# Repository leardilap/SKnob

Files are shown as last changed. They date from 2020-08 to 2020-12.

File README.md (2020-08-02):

# SKnob
The safety knob for your stove

# Overall shape
- Two main PCBs with 24x17mm dimmentions joined with ~~flex PCB~~ 2 wires

# Battery
- CR1225 or similar with ~50mA could allow to be mounted in the top of one of the PCBs as the space is round in the middle
- Holder: Manufacturer Part Number 	BK-885-TR 

# Bluetooth-STM32
- Use the STM32WB55Cx chip 
- Workshop: https://www.youtube.com/watch?v=5Lp9cDBzG94&list=PLnMKNibPkDnGRfqUO1Q_-1nW-tOKfDQbc&index=1

# Antena
- Manufacturer 	PulseLarsen Antennas
Manufacturer Part Number 	W3008 

# Similar product
- https://burneralert.com/

# Commercial
- Don't be a SKnob, do you mean our safety knobs for our burnner?. this is how I protect my family everyday, no more sleepless nights, waking up at night just to check the stove. With SKnob I feel safe. Don't wait, be a hero today.

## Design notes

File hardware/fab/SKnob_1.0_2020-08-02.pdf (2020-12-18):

SKnob | Rev: 1.0
bozica.co | 2020-08-02
| Sou rce d | Pla ced | References | digikey# | manf | manf# | datasheet | Value | Footprint | Quantity
1 | | | C1, C2, C3, C4, C7, C8, C11, C12, C14, C21, C22, C23, C24, C27 | | | | | 100nF | C_0402_1005Metric | 14
2 | | | C16, C18 | | | | | 15pF | C_0402_1005Metric | 2
3 | | | C17, C19 | | | | | 9pF | C_0402_1005Metric | 2
4 | | | C5 | | | | | 100pF | C_0402_1005Metric | 1
5 | | | C6, C13, C15, C20, C25, C26 | | | | | 4.7uF | C_0805_2012Metric | 6
6 | | | R2, R4 | | | | | 10k | R_0402_1005Metric | 2
7 | | | R1 | | | | | 10M | R_0402_1005Metric | 1
8 | | | L1, L2 | 445-172893-1-ND | TDK Corporation | 445-172893-1-ND | https://product.tdk.com/info/en/catalog/datasheets/beads_automotive_power_mpz1608_en.pdf | 220 @ 100MHz | L_0603_1608Metric | 2
9 | | | L4 | 587-1720-1-ND | Taiyo Yuden | CBMF1608T100K | https://www.yuden.co.jp/productdata/catalog/wound02_e.pdf | 10uH | L_0603_1608Metric | 1
10 | | | D1 | 1N4148WL2-TPMSCT-ND | Micro Commercial Co | 1N4148WL2-TP | https://www.mccsemi.com/pdf/Products/1N4148WL2(DFN1006-2 L)-A.pdf | 1N4148 | D_0402_1005Metric | 1
11 | | | U2 | 497-15997-1-ND | STMicroelectronics | LIS2DE12TR | https://www.st.com/content/ccc/resource/technical/document/datasheet/group0/72/cb/80/a7/5e/fe/46/9d/DM00153214/files/DM00153214.pdf/jcr:content/translations/en.DM001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 | LIS2DE12TR | LIS2DE12TR | 1
12 | | | U1 | 497-18489-ND | STMicroelectronics | STM32WB55CGU6 | https://www.st.com/resource/en/datasheet/stm32wb55rg.pdf | STM32WB55Cx | STM32WB55Cx | 1
13 | | | U3 | 497-5026-1-ND | STMicroelectronics | USBLC6-2P6 | https://www.st.com/resource/en/datasheet/usblc6-2.pdf | USBLC6-2P6 | SOT-666 | 1
SKnob BOM | file:///home/lardilap/Projects/PCB/bozica/SKnob/hardware/fab/SKnob_1.0_2020-08-02.html
1 of 2 | 12/18/20, 10:32 AM

Sou
rce
d

Pla
ced | References | digikey# | manf | manf# | datasheet | Value | Footprint | Quantity
14 | Y1 | 490-18335-1-ND | Murata Electronics | XRCGB32M000F1H02R0

https://www.murata.c
om/products
/productdata
/8801065041950/SPEC-XRCGB32M000F1H02R0.p
df
32MHz | Crystal_SMD_2016-4Pi
n_2.0x1.6mm | 1
15 | Y2 | XC2744CT-ND | ECS Inc. | ECS-.327-9-12R-C-TR

https://www.ecsxtal.
com/store/pdf/ECX-12R.pdf
32.768kHz | Crystal_SMD_2012-2Pi
n_2.0x1.2mm | 1
16 | SW1 | SW1022CT-ND | Omron Electronics
Inc-EMC Div | B3U-3000P

https://omronfs.omro
n.com/en_US
/ecb/products
/pdf/en-b3u.pdf
SW_Push | SW_SPST_B3U-3000P | 1
17 | BZ1 | 2104-TE034003-1CT-ND | DB Unlimited | TE034003-1

https://dbunlimitedc
o.com/images
/product_images/2D-Drawings
/TE034003-1.pdf
TE034003-1 | TE034003-1 | 1
18 | FLT1 | 497-19088-1-ND | STMicroelectronics | MLPF-WB55-01E3

https://www.st.com
/resource
/en/datasheet/mlpf-wb55-01e3.pdf
MLPF-WB55-01E3 | MLPF-WB55-01E3 | 1
19 | ANT1 | 553-1530-1-ND | PulseLarsen Antennas | W3008

https://source.z2dat
a.com/2019/5/5/2/28
/32/733/W3008.pdf
W3008 | W3008 | 1
20 | BT1 | BK-885-CT-ND | MPD (Memory
Protection Devices) | BK-885-TR

https://www.memorypr
otectiondevices.com
/datasheets/BK-885-
datasheet.pdf
BK-885-TR | BatteryHolder_Keysto
ne_3000_1x12mm | 1
21 | Q1 | FDV301NCT-ND | ON Semiconductor | FDV301N

https://media.digike
y.com
/pdf/Data%20Sheets
/Fairchild%20PDFs
/FDV301N.pdf
FDV301N | SOT-23 | 1
22 | BATT1 | P183-ND | Panasonic - BSG | BR-1225

https://industrial.p
anasonic.com
/cdbs/www-data/pdf2
/AAA4000
/AAA4000C202.pdf
BR1225 | BR1225 | 1
23 | J2, J3 | 952-2280-ND | Harwin Inc. | M22-2510246 | https://cdn.harwin.c
om/pdfs/M22-251.pdf | Conn_01x02 | PinHeader_1x02_P2.00
mm_Vertical | 2
24 | J1 | WM9734CT-ND | Molex | 1051330001

https://www.molex.co
m/pdm_docs
/sd/1051330001_sd.pd
f
USB_B_Micro | USB_Micro-B_Molex-
105133-0001 | 1
SKnob BOM | file:///home/lardilap/Projects/PCB/bozica/SKnob/hardware/fab/SKnob_1.0_2020-08-02.html
2 of 2 | 12/18/20, 10:32 AM

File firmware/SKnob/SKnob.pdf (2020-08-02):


02/08/2020

## SKnob Project Configuration Report

# 1. Description

## 1.1. Project

Project Name | SKnob
Board Name | custom
Generated with: | STM32CubeMX 6.0.0
Date | 08/02/2020

## 1.2. MCU

MCU Series | STM32WB
MCU Line | STM32WBx5
MCU name | STM32WB55CCUx
MCU Package | UFQFPN48
MCU Pin number | 48

## 1.3. Core(s) information

Core(s) | ARM Cortex-M4

# 2. Pinout Configuration

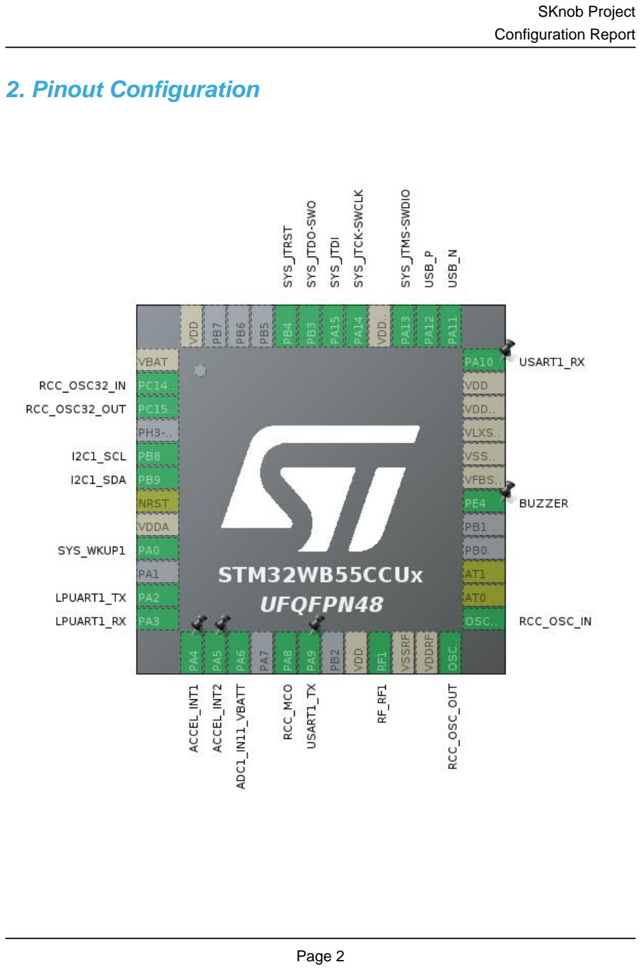
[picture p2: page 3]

# 3. Pins Configuration

Pin Number UFQFPN48 | Pin Name (function after reset) | Pin Type | Alternate Function(s) | Label
1 | VBAT | Power
2 | PC14-OSC32_IN | I/O | RCC_OSC32_IN
3 | PC15-OSC32_OUT | I/O | RCC_OSC32_OUT
5 | PB8 | I/O | I2C1_SCL
6 | PB9 | I/O | I2C1_SDA
7 | NRST | Reset
8 | VDDA | Power
9 | PA0 | I/O | SYS_WKUP1
11 | PA2 | I/O | LPUART1_TX
12 | PA3 | I/O | LPUART1_RX
13 | PA4 * | I/O | GPIO_Input | ACCEL_INT1
14 | PA5 * | I/O | GPIO_Input | ACCEL_INT2
15 | PA6 | I/O | ADC1_IN11 | ADC1_IN11_VBATT
17 | PA8 | I/O | RCC_MCO
18 | PA9 | I/O | USART1_TX
20 | VDD | Power
21 | RF1 | MonoIO | RF_RF1
22 | VSSRF | Power
23 | VDDRF | Power
24 | OSC_OUT | MonoIO | RCC_OSC_OUT
25 | OSC_IN | MonoIO | RCC_OSC_IN
26 | AT0 | NC
27 | AT1 | NC
30 | PE4 * | I/O | GPIO_Output | BUZZER
31 | VFBSMPS | Power
32 | VSSSMPS | Power
33 | VLXSMPS | Power
34 | VDDSMPS | Power
35 | VDD | Power
36 | PA10 | I/O | USART1_RX
37 | PA11 | I/O | USB_DM | USB_N
38 | PA12 | I/O | USB_DP | USB_P
39 | PA13 | I/O | SYS_JTMS-SWDIO
40 | VDDUSB | Power
41 | PA14 | I/O | SYS_JTCK-SWCLK
42 | PA15 | I/O | SYS_JTDI

Pin Number UFQFPN48 | Pin Name (function after reset) | Pin Type | Alternate Function(s) | Label
43 | PB3 | I/O | SYS_JTDO-SWO
44 | PB4 | I/O | SYS_JTRST
48 | VDD | Power

## * The pin is affected with an I/O function

# 4. Clock Tree Configuration

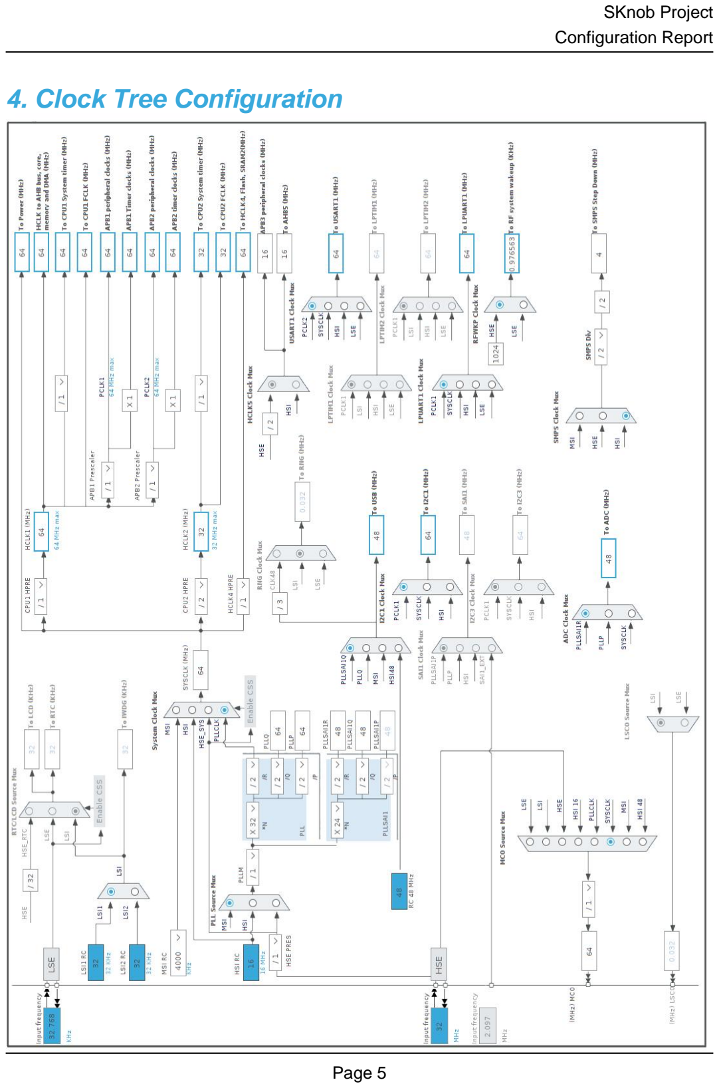
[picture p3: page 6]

# 5. Software Project

## 5.1. Project Settings

Name | Value
Project Name | SKnob
Project Folder | /home/luis/Projects/PCB/kicad/SKnob/firmware/SKnob
Toolchain / IDE | STM32CubeIDE
Firmware Package Name and Version | STM32Cube FW_WB V1.8.0
Application Structure | Basic
Generate Under Root | Yes
Do not generate the main() | No
Minimum Heap Size | 0x200
Minimum Stack Size | 0x400

## 5.2. Code Generation Settings

Name | Value
STM32Cube MCU packages and embedded software | Copy only the necessary library files
Generate peripheral initialization as a pair of '.c/.h' files | No
Backup previously generated files when re-generating | No
Keep User Code when re-generating | Yes
Delete previously generated files when not re-generated | Yes
Set all free pins as analog (to optimize the power consumption) | No
Enable Full Assert | No

## 5.3. Advanced Settings - Generated Function Calls

Rank | Function Name | IP Instance Name
1 | MX_GPIO_Init | GPIO
2 | SystemClock_Config | RCC
3 | MX_I2C1_Init | I2C1
4 | MX_USART1_UART_Init | USART1
5 | MX_USB_Device_Init | USB_DEVICE
6 | MX_ADC1_Init | ADC1
7 | MX_RF_Init | RF
8 | MX_LPUART1_UART_Init | LPUART1

# 6. Power Consumption Calculator report

## 6.1. Microcontroller Selection

Series | STM32WB
Line | STM32WBx5
MCU | STM32WB55CCUx
Datasheet | DS11929_Rev3

## 6.2. Parameter Selection

Temperature | 25
Vdd | 3.0

## 6.3. Battery Selection

Battery | Li-SOCL2(A3400)
Capacity | 3400.0 mAh
Self Discharge | 0.08 %/month
Nominal Voltage | 3.6 V
Max Cont Current | 100.0 mA
Max Pulse Current | 200.0 mA
Cells in series | 1
Cells in parallel | 1

## 6.4. Sequence

Step | Step1 | Step2
Mode | RUN | STOP2
Vdd | 3.0 | 3.0
Voltage Source | Battery | Battery
Range | Range1-High | NoRange/SMPS
Fetch Type | SRAM1 Flash-PowerDown | FLASH/ART/CACHE/BLE
CPU Frequency | 64 MHz | 0 Hz
Clock Configuration | HSI PLL Regulator_ON | ALL CLOCKS OFF BLE Regulator_ON
Clock Source Frequency | 16 MHz | 0 Hz

### Peripherals

Additional Cons. | 0 mA | 0 mA
Average Current | 8.8 mA | 1 nA
Duration | 0.1 ms | 0.9 ms
DMIPS | 80.0 | 0.0
Ta Max | 104.34 | 105
Category | In DS Table | In DS Table

## 6.5. Results

Sequence Time | 1 ms | Average Current | 880 µA
Battery Life | 5 months, 8 days, 5 hours | Average DMIPS | 8.0 DMIPS

## 6.6. Chart

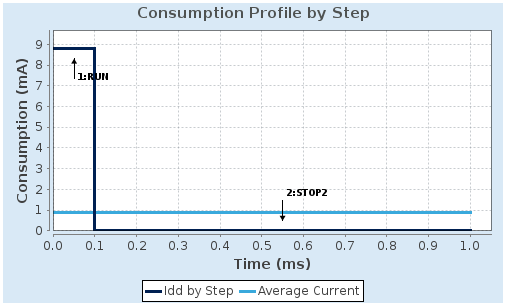
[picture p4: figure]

# 7. IPs and Middleware Configuration

## 7.1. ADC1 IN11: IN11 Single-ended mode: Vbat Channel

## 7.1.1. Parameter Settings:

### ADC_Settings:

Clock Prescaler | Asynchronous clock mode divided by 1
Resolution | ADC 12-bit resolution
Data Alignment | Right alignment
Scan Conversion Mode | Disabled
Continuous Conversion Mode | Disabled
Discontinuous Conversion Mode | Disabled
DMA Continuous Requests | Disabled
End Of Conversion Selection | End of single conversion
Overrun behaviour | Overrun data preserved
Low Power Auto Wait | Disabled

### ADC_Regular_ConversionMode:

Enable Regular Conversions | Enable
Enable Regular Oversampling | Disable
Number Of Conversion | 1
External Trigger Conversion Source | Regular Conversion launched by software
External Trigger Conversion Edge | None
Rank | 1
Channel | Channel 11
Sampling Time | 2.5 Cycles
Offset Number | No offset

### ADC_Injected_ConversionMode:

Enable Injected Conversions | Disable

### Analog Watchdog 1:

Enable Analog WatchDog1 Mode | false

### Analog Watchdog 2:

Enable Analog WatchDog2 Mode | false

### Analog Watchdog 3:

Enable Analog WatchDog3 Mode | false

## 7.2. GPIO

## 7.3. I2C1 I2C: I2C

## 7.3.1. Parameter Settings:

### Timing configuration:

Custom Timing | Disabled
I2C Speed Mode | Standard Mode
I2C Speed Frequency (KHz) | 100
Rise Time (ns) | 0
Fall Time (ns) | 0
Coefficient of Digital Filter | 0
Analog Filter | Enabled
Timing | 0x10707DBC *

### Slave Features:

Clock No Stretch Mode | Disabled
General Call Address Detection | Disabled
Primary Address Length selection | 7-bit
Dual Address Acknowledged | Disabled
Primary slave address | 0

## 7.4. LPUART1 Mode: Asynchronous

## 7.4.1. Parameter Settings:

### Basic Parameters:

Baud Rate | 209700
Word Length | 8 Bits (including Parity)
Parity | None
Stop Bits | 1

### Advanced Parameters:

Data Direction | Receive and Transmit
Single Sample | Disable
Prescaler | clock /1
Fifo Mode | FIFO mode disable
Txfifo Threshold | 1 eighth full configuration
Rxfifo Threshold | 1 eighth full configuration

### Advanced Features:

TX Pin Active Level Inversion | Disable

RX Pin Active Level Inversion | Disable
Data Inversion | Disable
TX and RX pins Swapping | Disable
Overrun | Enable
DMA on RX Error | Enable
MSB First | Disable

## 7.5. RCC High Speed Clock (HSE): Crystal/Ceramic Resonator Low Speed Clock (LSE) : Crystal/Ceramic Resonator mode: Master Clock Output

## 7.5.1. Parameter Settings:

### System Parameters:

VDD voltage (V) | 3.3
Instruction Cache | Enabled
Prefetch Buffer | Disabled
Data Cache | Enabled
Flash Latency(WS) | 3 WS (4 CPU cycle)

### RCC Parameters:

HSI Calibration Value | 16
MSI Calibration Value | 0
MSI Auto Calibration | Enabled
MSI State | Enabled
HSI State | Enabled
HSE Startup Timout Value (ms) | 100
LSE Startup Timout Value (ms) | 5000
LSE Drive Capability | LSE oscillator low drive capability

### Power Parameters:

Power Regulator Voltage Scale | Power Regulator Voltage Scale 1

### Peripherals Clock Configuration:

Generate the peripherals clock configuration | TRUE

## 7.6. RF mode: Activate RF1

## 7.7. SYS Debug: JTAG (5 pins) mode: System Wake-Up 1 Timebase Source: TIM17

## 7.8. USART1 Mode: Asynchronous

## 7.8.1. Parameter Settings:

### Basic Parameters:

Baud Rate | 115200
Word Length | 8 Bits (including Parity)
Parity | None
Stop Bits | 1

### Advanced Parameters:

Data Direction | Receive and Transmit
Over Sampling | 16 Samples
Single Sample | Disable
ClockPrescaler | clock /1
Fifo Mode | Disable
Txfifo Threshold | 1 eighth full configuration
Rxfifo Threshold | 1 eighth full configuration

### Advanced Features:

Auto Baudrate | Disable
TX Pin Active Level Inversion | Disable
RX Pin Active Level Inversion | Disable
Data Inversion | Disable
TX and RX Pins Swapping | Disable
Overrun | Enable
DMA on RX Error | Enable
MSB First | Disable

## 7.9. USB mode: Device (FS)

## 7.9.1. Parameter Settings:

### Basic Parameters:

Speed | Full Speed 12MBit/s

Physical interface | Internal Phy
Sof Enable | Disabled

### Power Parameters:

Low Power | Disabled
Link Power Management | Disabled
Battery Charging | Disabled

## 7.10. FREERTOS Interface: CMSIS_V2

## 7.10.1. Config parameters:

### API:

FreeRTOS API | CMSIS v2

### Versions:

FreeRTOS version | 10.2.1
CMSIS-RTOS version | 2.00

### MPU/FPU:

ENABLE_MPU | Disabled
ENABLE_FPU | Disabled

### Kernel settings:

USE_PREEMPTION | Enabled
CPU_CLOCK_HZ | SystemCoreClock
TICK_RATE_HZ | 1000
MAX_PRIORITIES | 56
MINIMAL_STACK_SIZE | 128
MAX_TASK_NAME_LEN | 16
USE_16_BIT_TICKS | Disabled
IDLE_SHOULD_YIELD | Enabled
USE_MUTEXES | Enabled
USE_RECURSIVE_MUTEXES | Enabled
USE_COUNTING_SEMAPHORES | Enabled
QUEUE_REGISTRY_SIZE | 8
USE_APPLICATION_TASK_TAG | Disabled
ENABLE_BACKWARD_COMPATIBILITY | Enabled
USE_PORT_OPTIMISED_TASK_SELECTION | Disabled
USE_TICKLESS_IDLE | Disabled
USE_TASK_NOTIFICATIONS | Enabled
RECORD_STACK_HIGH_ADDRESS | Disabled
OVERRIDE_DEFAULT_TICK_CONFIGURATION | Disabled

### Memory management settings:

Memory Allocation | Dynamic / Static
TOTAL_HEAP_SIZE | 3072
Memory Management scheme | heap_4

### Hook function related definitions:

USE_IDLE_HOOK | Disabled
USE_TICK_HOOK | Disabled
USE_MALLOC_FAILED_HOOK | Disabled
USE_DAEMON_TASK_STARTUP_HOOK | Disabled
CHECK_FOR_STACK_OVERFLOW | Disabled

### Run time and task stats gathering related definitions:

GENERATE_RUN_TIME_STATS | Disabled
USE_TRACE_FACILITY | Enabled
USE_STATS_FORMATTING_FUNCTIONS | Disabled

### Co-routine related definitions:

USE_CO_ROUTINES | Disabled
MAX_CO_ROUTINE_PRIORITIES | 2

### Software timer definitions:

USE_TIMERS | Enabled
TIMER_TASK_PRIORITY | 2
TIMER_QUEUE_LENGTH | 10
TIMER_TASK_STACK_DEPTH | 256

### Interrupt nesting behaviour configuration:

LIBRARY_LOWEST_INTERRUPT_PRIORITY | 15
LIBRARY_MAX_SYSCALL_INTERRUPT_PRIORITY | 5

### Added with 10.2.1 support:

MESSAGE_BUFFER_LENGTH_TYPE | size_t
USE_POSIX_ERRNO | Disabled

## 7.10.2. Include parameters:

### Include definitions:

vTaskPrioritySet | Enabled
uxTaskPriorityGet | Enabled
vTaskDelete | Enabled
vTaskCleanUpResources | Disabled
vTaskSuspend | Enabled
vTaskDelayUntil | Enabled
vTaskDelay | Enabled
xTaskGetSchedulerState | Enabled
xTaskResumeFromISR | Enabled
xQueueGetMutexHolder | Enabled

xSemaphoreGetMutexHolder | Disabled
pcTaskGetTaskName | Disabled
uxTaskGetStackHighWaterMark | Enabled
xTaskGetCurrentTaskHandle | Disabled
eTaskGetState | Enabled
xEventGroupSetBitFromISR | Disabled
xTimerPendFunctionCall | Enabled
xTaskAbortDelay | Disabled
xTaskGetHandle | Disabled
uxTaskGetStackHighWaterMark2 | Disabled

## 7.10.3. Advanced settings:

### Newlib settings (see parameter description first):

USE_NEWLIB_REENTRANT | Disabled

### Project settings (see parameter description first):

Use FW pack heap file | Enabled

## 7.11. USB_DEVICE Class For FS IP: Custom Human Interface Device Class (HID)

## 7.11.1. Parameter Settings:

### Class Parameters:

CUSTOM_HID_FS_BINTERVAL | 0x5 *
USBD_CUSTOM_HID_REPORT_DESC_SIZE (Total length for Report descriptor (IN ENDPOINT)) | 2
USBD_CUSTOMHID_OUTREPORT_BUF_SIZE (Maximum report buffer size (OUT ENDPOINT)) | 2

### Basic Parameters:

USBD_MAX_NUM_INTERFACES (Maximum number of supported interfaces) | 1
USBD_MAX_NUM_CONFIGURATION (Maximum number of supported configuration) | 1
USBD_MAX_STR_DESC_SIZ (Maximum size for the string descriptors) | 512
USBD_SELF_POWERED (Enabled self power) | Enabled
USBD_DEBUG_LEVEL (USBD Debug Level) | 0: No debug message
USBD_LPM_ENABLED (Link Power Management) | 1: Link Power Management supported

## 7.11.2. Device Descriptor:

### Device Descriptor:

VID (Vendor IDentifier) | 1155
LANGID_STRING (Language Identifier) | English(United States)
MANUFACTURER_STRING (Manufacturer Identifier) | STMicroelectronics

### Device Descriptor FS:

PID (Product IDentifier) | 22352 *
PRODUCT_STRING (Product Identifier) | STM32 Custom Human interface
CONFIGURATION_STRING (Configuration Identifier) | Custom HID Config
INTERFACE_STRING (Interface Identifier) | Custom HID Interface

### * User modified value

# 8. System Configuration

## 8.1. GPIO configuration

IP | Pin | Signal | GPIO mode | GPIO pull/up pull down | Max Speed | User Label
ADC1 | PA6 | ADC1_IN11 | Analog mode | No pull-up and no pull-down | n/a | ADC1_IN11_VBATT
I2C1 | PB8 | I2C1_SCL | Alternate Function Open Drain | Pull-up | Low
| PB9 | I2C1_SDA | Alternate Function Open Drain | Pull-up | Low
LPUART1 | PA2 | LPUART1_TX | Alternate Function Push Pull | No pull-up and no pull-down | Low
| PA3 | LPUART1_RX | Alternate Function Push Pull | No pull-up and no pull-down | Low
RCC | PC14-OSC32_IN | RCC_OSC32_IN | n/a | n/a | n/a
| PC15-OSC32_OU T | RCC_OSC32_O UT | n/a | n/a | n/a
| PA8 | RCC_MCO | Alternate Function Push Pull | No pull-up and no pull-down | Low
| OSC_OUT | RCC_OSC_OUT | n/a | n/a | n/a
| OSC_IN | RCC_OSC_IN | n/a | n/a | n/a
RF | RF1 | RF_RF1 | n/a | n/a | n/a
SYS | PA0 | SYS_WKUP1 | n/a | n/a | n/a
| PA13 | SYS_JTMS-SWDIO | n/a | n/a | n/a
| PA14 | SYS_JTCK-SWCLK | n/a | n/a | n/a
| PA15 | SYS_JTDI | n/a | n/a | n/a
| PB3 | SYS_JTDO-SWO | n/a | n/a | n/a
| PB4 | SYS_JTRST | n/a | n/a | n/a
USART1 | PA9 | USART1_TX | Alternate Function Push Pull | No pull-up and no pull-down | Low
| PA10 | USART1_RX | Alternate Function Push Pull | No pull-up and no pull-down | Low
USB | PA11 | USB_DM | Alternate Function Push Pull | No pull-up and no pull-down | Low | USB_N
| PA12 | USB_DP | Alternate Function Push Pull | No pull-up and no pull-down | Low | USB_P
GPIO | PA4 | GPIO_Input | Input mode | No pull-up and no pull-down | n/a | ACCEL_INT1
| PA5 | GPIO_Input | Input mode | No pull-up and no pull-down | n/a | ACCEL_INT2
| PE4 | GPIO_Output | Output Push Pull | No pull-up and no pull-down | Low | BUZZER

## 8.2. DMA configuration

## nothing configured in DMA service

## 8.3. NVIC configuration

## 8.3.1. NVIC

Interrupt Table | Enable | Preenmption Priority | SubPriority
Non maskable interrupt | true | 0 | 0
Hard fault interrupt | true | 0 | 0
Memory management fault | true | 0 | 0
Prefetch fault, memory access fault | true | 0 | 0
Undefined instruction or illegal state | true | 0 | 0
System service call via SWI instruction | true | 0 | 0
Debug monitor | true | 0 | 0
Pendable request for system service | true | 0 | 0
System tick timer | true | 0 | 0
USB low priority interrupt, USB wake-up interrupt through EXTI line 28 | true | 0 | 0
TIM1 trigger and commutation interrupts and TIM17 global interrupt | true | 0 | 0
PVD/PVM0/PVM2 interrupts through EXTI lines 16/31/33 | | unused
Flash global interrupt | | unused
RCC global interrupt | | unused
ADC1 global interrupt | | unused
USB high priority interrupt | | unused
CPU2 SEV interrupt through EXTI line 40 and PWR CPU2 HOLD wake-up interrupt | | unused
I2C1 event interrupt | | unused
I2C1 error interrupt | | unused
USART1 global interrupt | | unused
LPUART1 global interrupt | | unused
PWR switching on the fly, end of BLE activity, end of 802.15.4 activity, end of critical radio phase interrupt | | unused
FPU global interrupt | unused

## 8.3.2. NVIC Code generation

## Enabled interrupt Table Select for init sequence ordering Generate IRQ handler

## Call HAL handler

Non maskable interrupt | true | true | false
Hard fault interrupt | true | true | false
Memory management fault | true | true | false
Prefetch fault, memory access fault | true | true | false
Undefined instruction or illegal state | true | true | false

Enabled interrupt Table | Select for init sequence ordering | Generate IRQ handler | Call HAL handler
System service call via SWI instruction | true | false | false
Debug monitor | true | true | false
Pendable request for system service | true | false | false
System tick timer | true | false | false
USB low priority interrupt, USB wake-up interrupt through EXTI line 28 | true | true | true
TIM1 trigger and commutation interrupts and TIM17 global interrupt | true | true | true

### * User modified value

# 9. System Views

## 9.1. Category view 9.1.1. Current

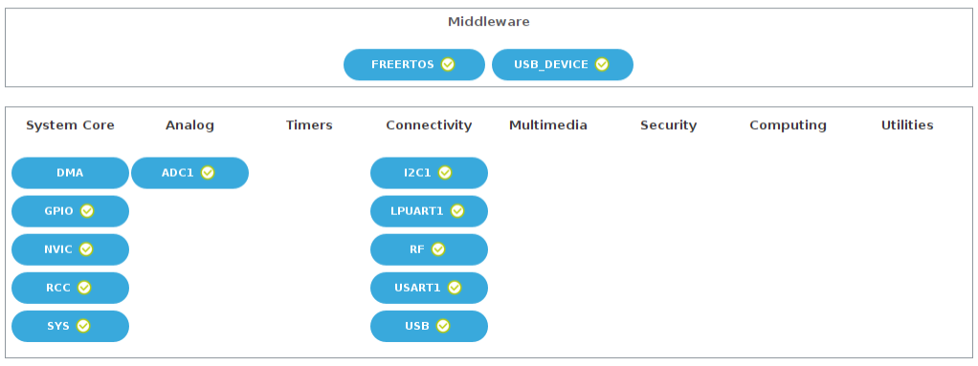
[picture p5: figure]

# 10. Software Pack Report

## 10.1. Software Pack selected

Vendor | Name | Version | Component
STMicroelectronic s | FreeRTOS | 0.0.1 | Class : CMSIS Group : RTOS2 SubGroup : FreeRTOS Version : 10.2.0 Class : RTOS Group : Core Version : 10.2.0
STMicroelectronic s | USB_DEVICE | 3.0.0 | Class : USB Group : USB Device SubGroup : Custom HID FS Version : 3.0

# 11. Docs & Resources

Type | Link
Datasheet | http://www.st.com/resource/en/datasheet/DM00344191.pdf
Reference manual | http://www.st.com/resource/en/reference_manual/DM00318631.pdf
Programming manual | http://www.st.com/resource/en/programming_manual/DM00046982.pdf
Programming manual | http://www.st.com/resource/en/programming_manual/DM00104451.pdf
Errata sheet | http://www.st.com/resource/en/errata_sheet/DM00383256.pdf
Application note | http://www.st.com/resource/en/application_note/CD00167594.pdf
Application note | http://www.st.com/resource/en/application_note/CD00211314.pdf
Application note | http://www.st.com/resource/en/application_note/CD00264342.pdf
Application note | http://www.st.com/resource/en/application_note/CD00264379.pdf
Application note | http://www.st.com/resource/en/application_note/DM00042534.pdf
Application note | http://www.st.com/resource/en/application_note/DM00072315.pdf
Application note | http://www.st.com/resource/en/application_note/DM00073742.pdf
Application note | http://www.st.com/resource/en/application_note/DM00081379.pdf
Application note | http://www.st.com/resource/en/application_note/DM00085385.pdf
Application note | http://www.st.com/resource/en/application_note/DM00087593.pdf
Application note | http://www.st.com/resource/en/application_note/DM00151811.pdf
Application note | http://www.st.com/resource/en/application_note/DM00160482.pdf
Application note | http://www.st.com/resource/en/application_note/DM00220769.pdf
Application note | http://www.st.com/resource/en/application_note/DM00227538.pdf
Application note | http://www.st.com/resource/en/application_note/DM00257177.pdf
Application note | http://www.st.com/resource/en/application_note/DM00272912.pdf
Application note | http://www.st.com/resource/en/application_note/DM00226326.pdf
Application note | http://www.st.com/resource/en/application_note/DM00236305.pdf
Application note | http://www.st.com/resource/en/application_note/DM00355687.pdf

Application note | http://www.st.com/resource/en/application_note/DM00311483.pdf
Application note | http://www.st.com/resource/en/application_note/DM00315319.pdf
Application note | http://www.st.com/resource/en/application_note/DM00380469.pdf
Application note | http://www.st.com/resource/en/application_note/DM00470410.pdf
Application note | http://www.st.com/resource/en/application_note/DM00395696.pdf
Application note | http://www.st.com/resource/en/application_note/DM00493651.pdf
Application note | http://www.st.com/resource/en/application_note/DM00535045.pdf
Application note | http://www.st.com/resource/en/application_note/DM00504903.pdf
Application note | http://www.st.com/resource/en/application_note/DM00556293.pdf
Application note | http://www.st.com/resource/en/application_note/DM00600032.pdf
Application note | http://www.st.com/resource/en/application_note/DM00403796.pdf
Application note | http://www.st.com/resource/en/application_note/DM00429003.pdf
Application note | http://www.st.com/resource/en/application_note/DM00513965.pdf
Application note | http://www.st.com/resource/en/application_note/DM00536349.pdf
Application note | http://www.st.com/resource/en/application_note/DM00556294.pdf
Application note | http://www.st.com/resource/en/application_note/DM00571230.pdf
Application note | http://www.st.com/resource/en/application_note/DM00600575.pdf
Application note | http://www.st.com/resource/en/application_note/DM00492814.pdf
Application note | http://www.st.com/resource/en/application_note/DM00598033.pdf
Application note | http://www.st.com/resource/en/application_note/DM00642959.pdf
Application note | http://www.st.com/resource/en/application_note/DM00643581.pdf
Application note | http://www.st.com/resource/en/application_note/DM00674475.pdf
Application note | http://www.st.com/resource/en/application_note/DM00652728.pdf
Application note | http://www.st.com/resource/en/application_note/DM00704246.pdf

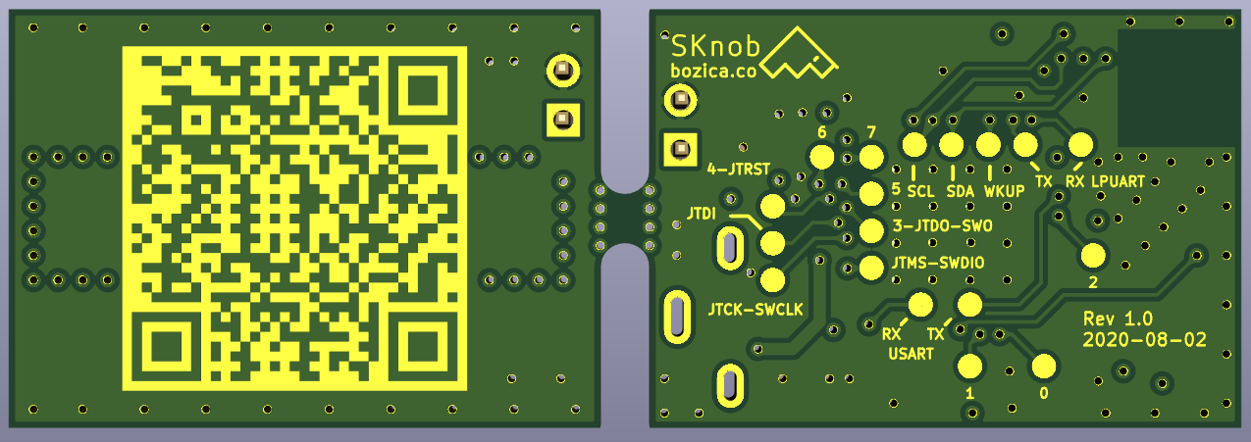
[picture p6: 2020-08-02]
hardware/images/PCB_3D_BOTTOM.png

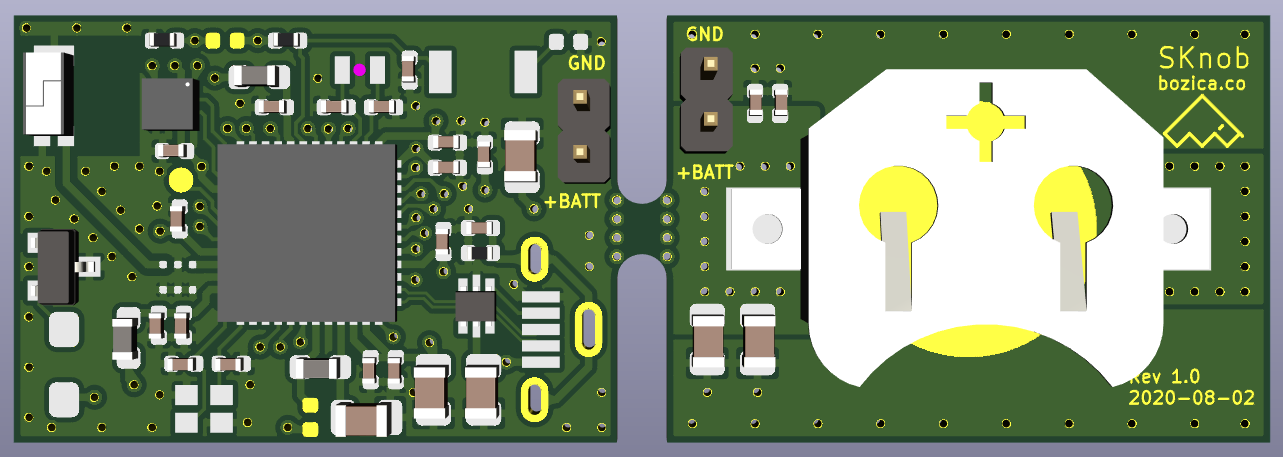
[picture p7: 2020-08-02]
hardware/images/PCB_3D_TOP.png

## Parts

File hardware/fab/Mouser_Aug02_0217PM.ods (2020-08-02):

SHOPPING BASKET
This is not an invoice
02-Aug-20 14:17:06
 | Mouser No | Mfr. No | Manufacturer | Customer No | Description | RoHS | Lifecycle | Order Qty. | Price (EUR) | Ext.: (EUR)
1 | 511-LIS2DE12TR | LIS2DE12TR | STMicroelectronics |  | Accelerometers CONSUMER MEMS | RoHS Compliant |  | 10 | 1,01 € | 10,10 €
2 | 673-W3008 | W3008 | Pulse |  | Antennas 2.4GHz BlueTooth Ceramic Antenna | RoHS Compliant |  | 10 | 1,12 € | 11,20 €
3 | 538-105133-0001 | 105133-0001 | Molex |  | USB Connectors MICRO USB B RECPT VERTICAL | RoHS Compliant |  | 10 | 0,80 € | 8,00 €
4 | 963-CBMF1608T100K | CBMF1608T100K | Taiyo Yuden |  | Fixed Inductors 0603 10uH 468mOhms +/-10% 115mA | RoHS Compliant |  | 10 | 0,139 € | 1,39 €
By submitting your order you agree to these terms and conditions. (https://www.mouser.de/saleterms) |  |  |  |  |  |  |  |  | Merchandise Total: | 30,69 €
Prices are reflected at the date and time shown. |  |  |  |  |  |  |  |  | Delivery Charge: | 20,00 €

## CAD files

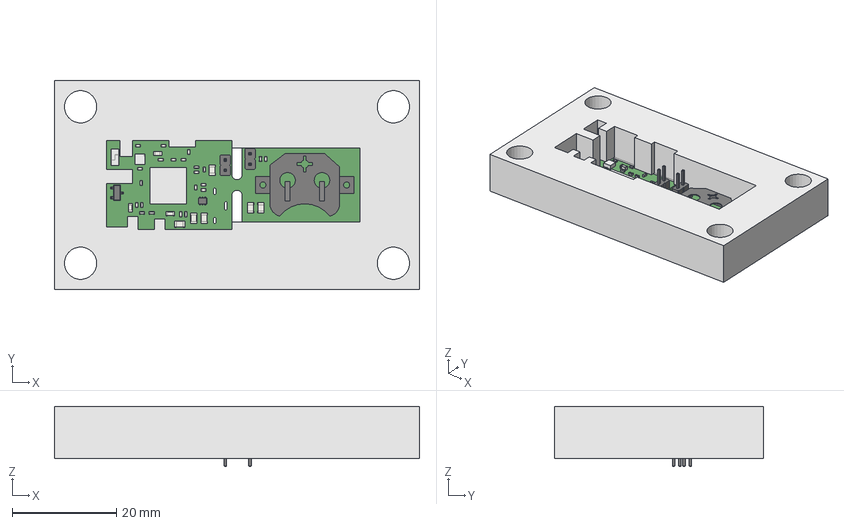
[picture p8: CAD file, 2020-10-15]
hardware/sknob-programmer/mech/Holder.FCStd
70.0 x 40.0 x 11.6 mm

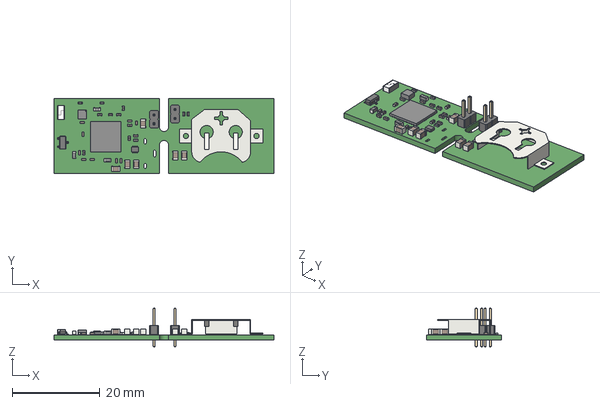
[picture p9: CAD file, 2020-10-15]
hardware/SKnob.step
50.0 x 17.0 x 8.80 mm

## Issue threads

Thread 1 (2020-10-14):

Replace USBLC6-2P6 with PESD5V0U5BV

leardilap, 2020-10-14:
The USBLC6-2P6 has pins 1&6 and 3&4 internally connected, pass-through routing of 2 signals only is allowed, if replaced with PESD5V0U5BV there is no need to do patch or PCB modification.

Digi-key 1727-5806-1-ND

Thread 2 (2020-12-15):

[Feature] AC-DC module for IoT version

leardilap, 2020-12-15:
IoT Sknob

Digi-Key Part Number  2725-LS01-K3B05SS-ND

Mornsun America, LLC
LS01-K3B05SS

leardilap, 2021-09-01:
Digi-Key Part Number | Z2985-ND |  
Omron Automation and Safety |  
G3MC-202P DC5 |  
SSR RELAY SPST-NO 2A 75-264V

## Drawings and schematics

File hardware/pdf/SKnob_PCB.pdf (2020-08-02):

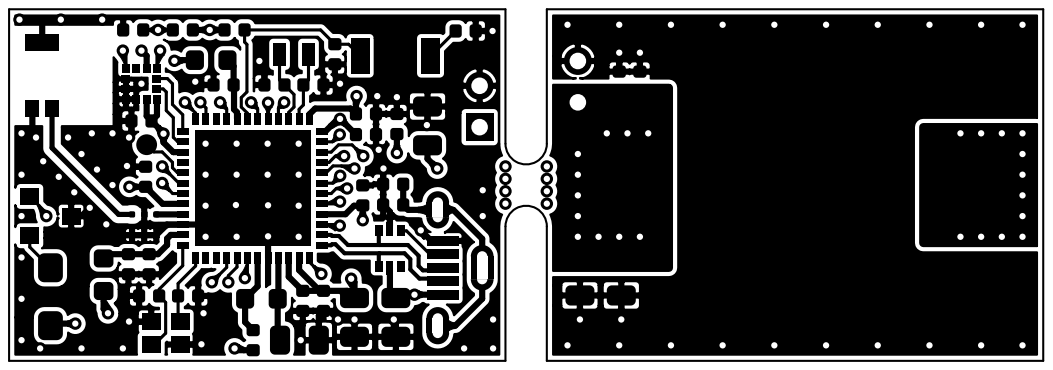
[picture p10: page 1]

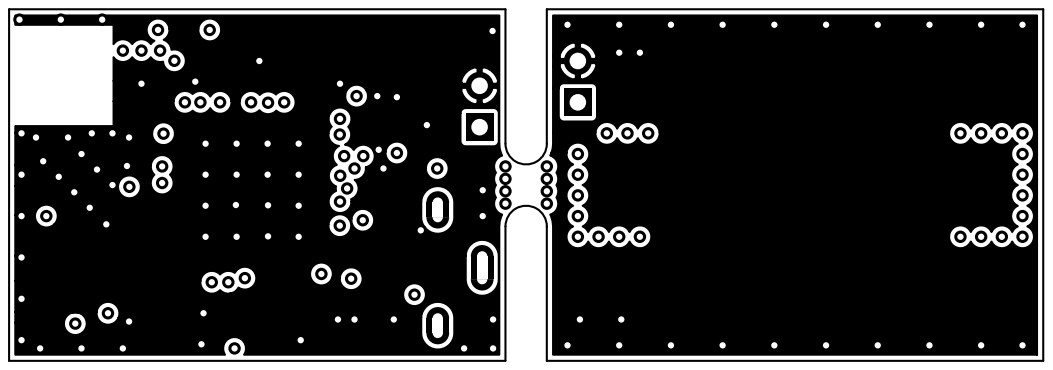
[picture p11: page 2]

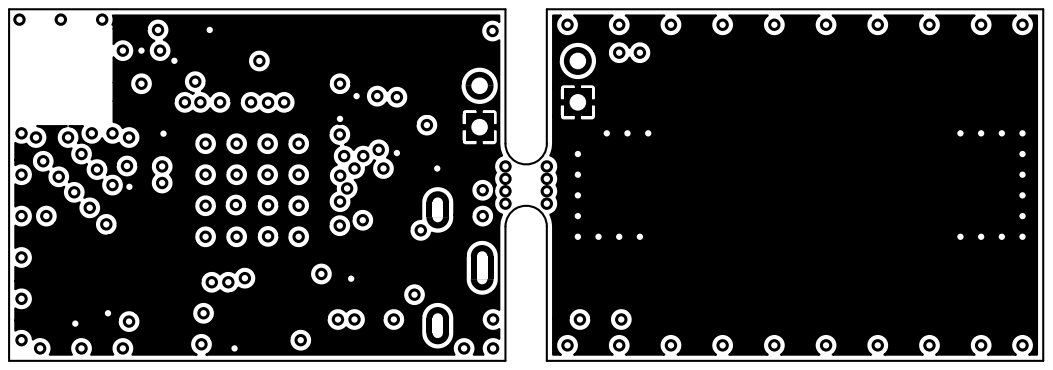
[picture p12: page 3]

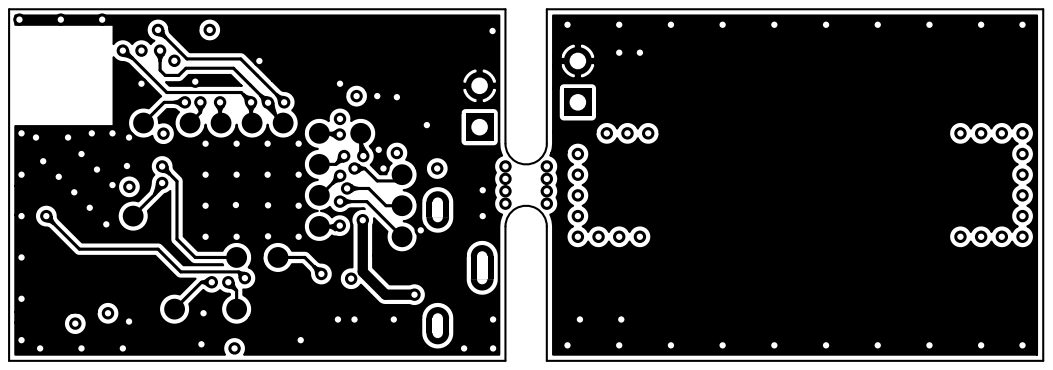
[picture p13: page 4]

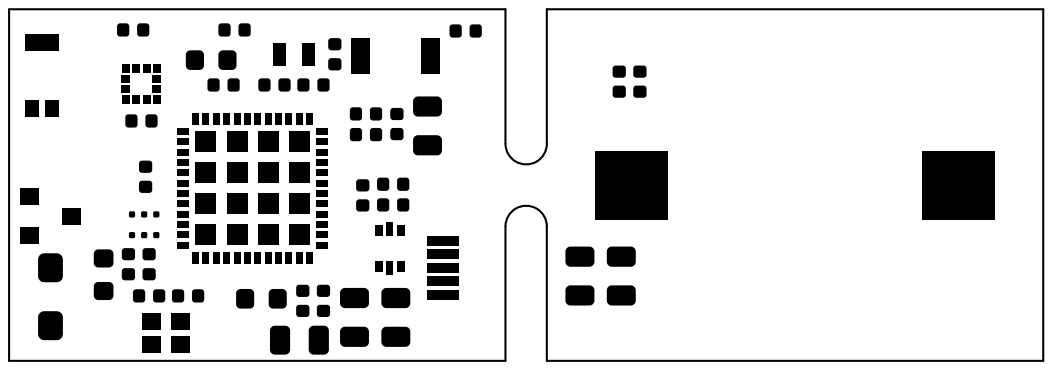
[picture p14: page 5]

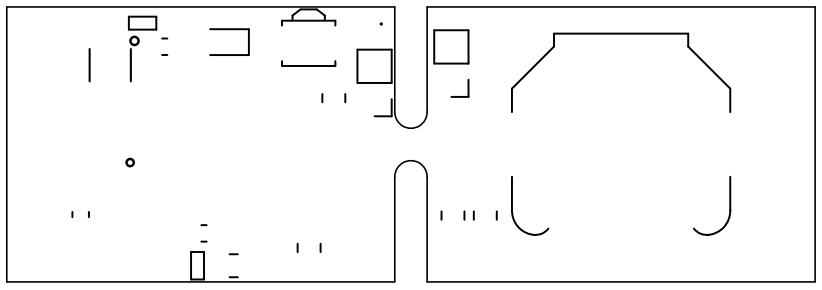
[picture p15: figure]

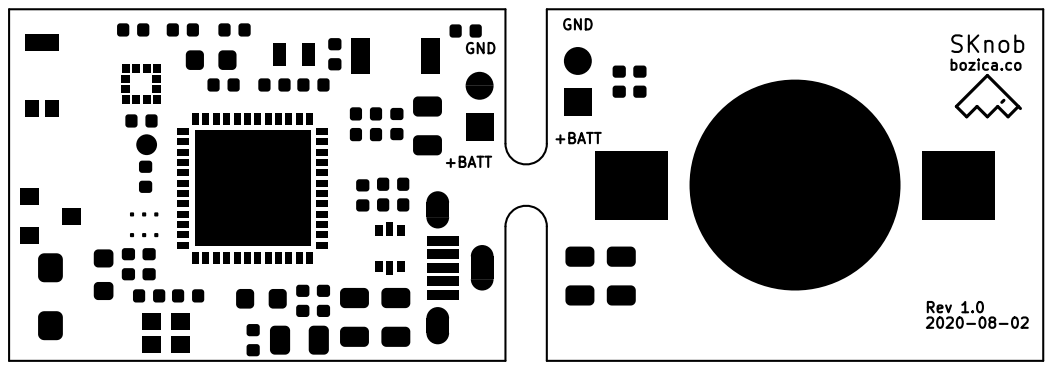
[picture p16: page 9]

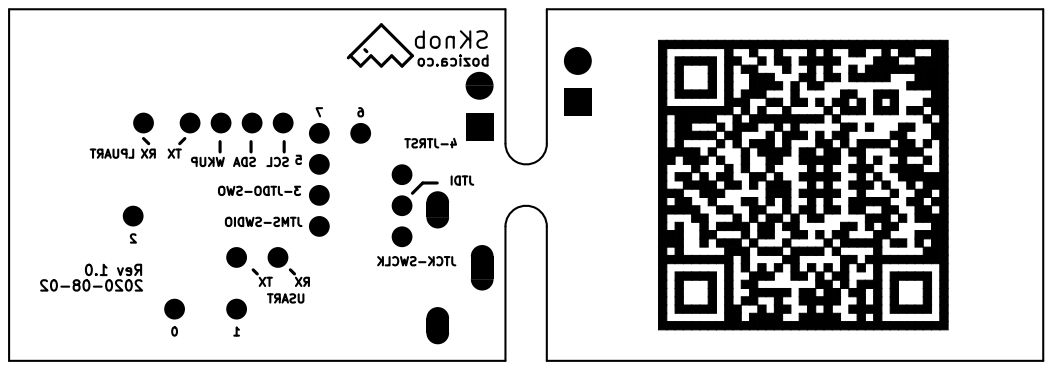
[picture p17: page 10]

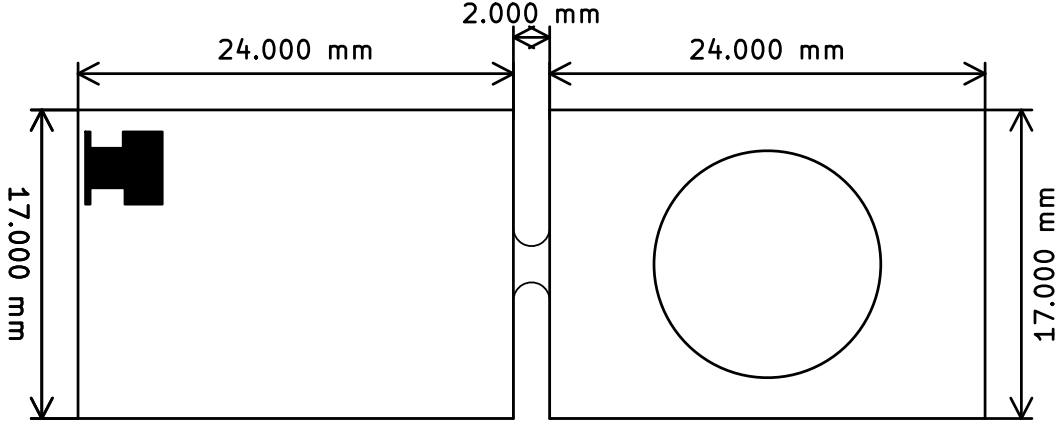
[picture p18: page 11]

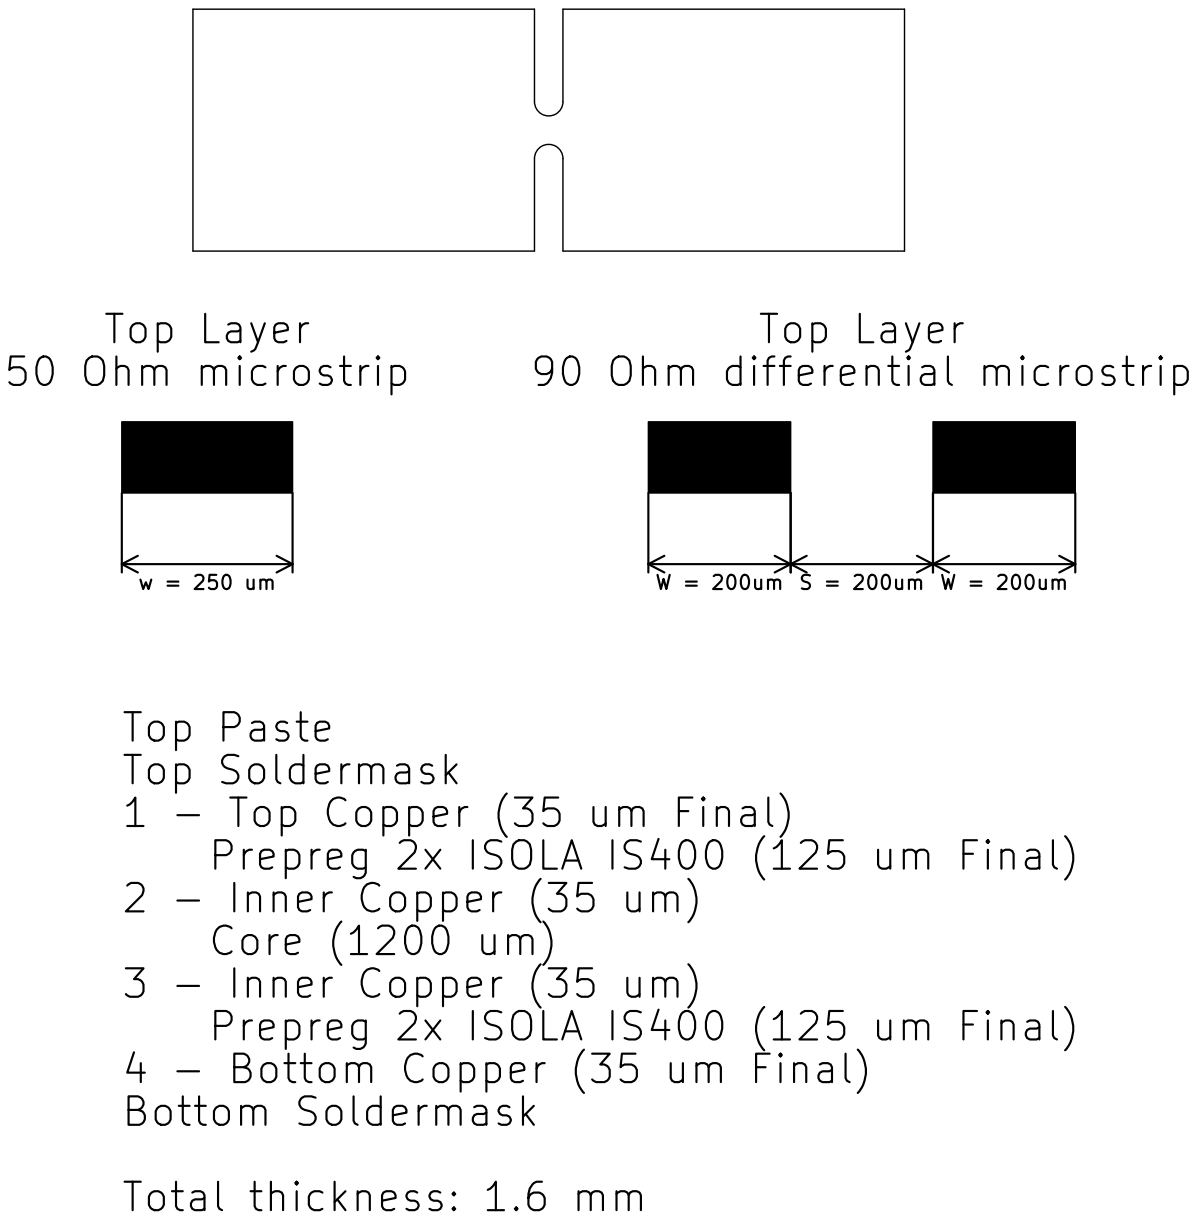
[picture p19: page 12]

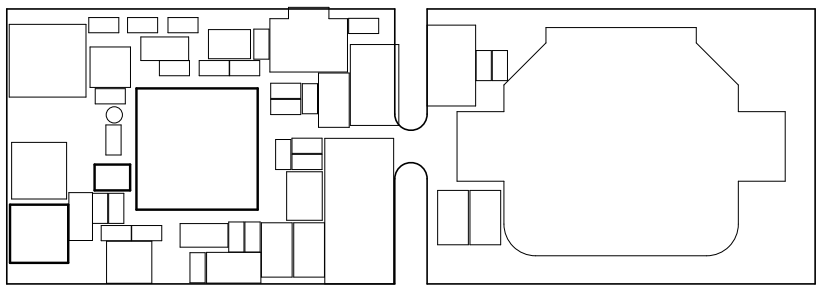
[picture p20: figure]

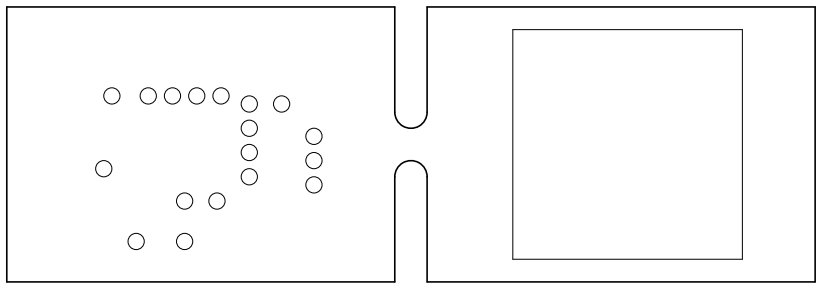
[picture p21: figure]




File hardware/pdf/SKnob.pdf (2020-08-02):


1 PA1 10 PA2 11 PA3 12 PA4 13 PA5 14 PA6 15 PA7 16 PA8 17 PA9 18 PB2 19 PC14-OSC32_IN 2 VDD 20 RF1 21 VSSRF 22 VDDRF 23 OSC_OUT 24 OSC_IN 25 AT0 26 AT1 27 PB0 28 PB1 29 PC15-OSC32_OUT 3 PE4 30 VFBSMPS 31 VSSSMPS 32 VLXSMPS 33 VDDSMPS 34 VDD 35 PA10 36 PA11 37 PA12 38 PA13 39 PH3-BOOT0 4 VDDUSB 40 PA14 41 PA15 42 PB3 43 PB4 44 PB5 45 PB6 46 PB7 47 VDD 48 EPAD 49 PB8 5 PB9 6 NRST 7 VDDA

Luis Ardila
File: SKnob.sch Sheet: / bozica.co

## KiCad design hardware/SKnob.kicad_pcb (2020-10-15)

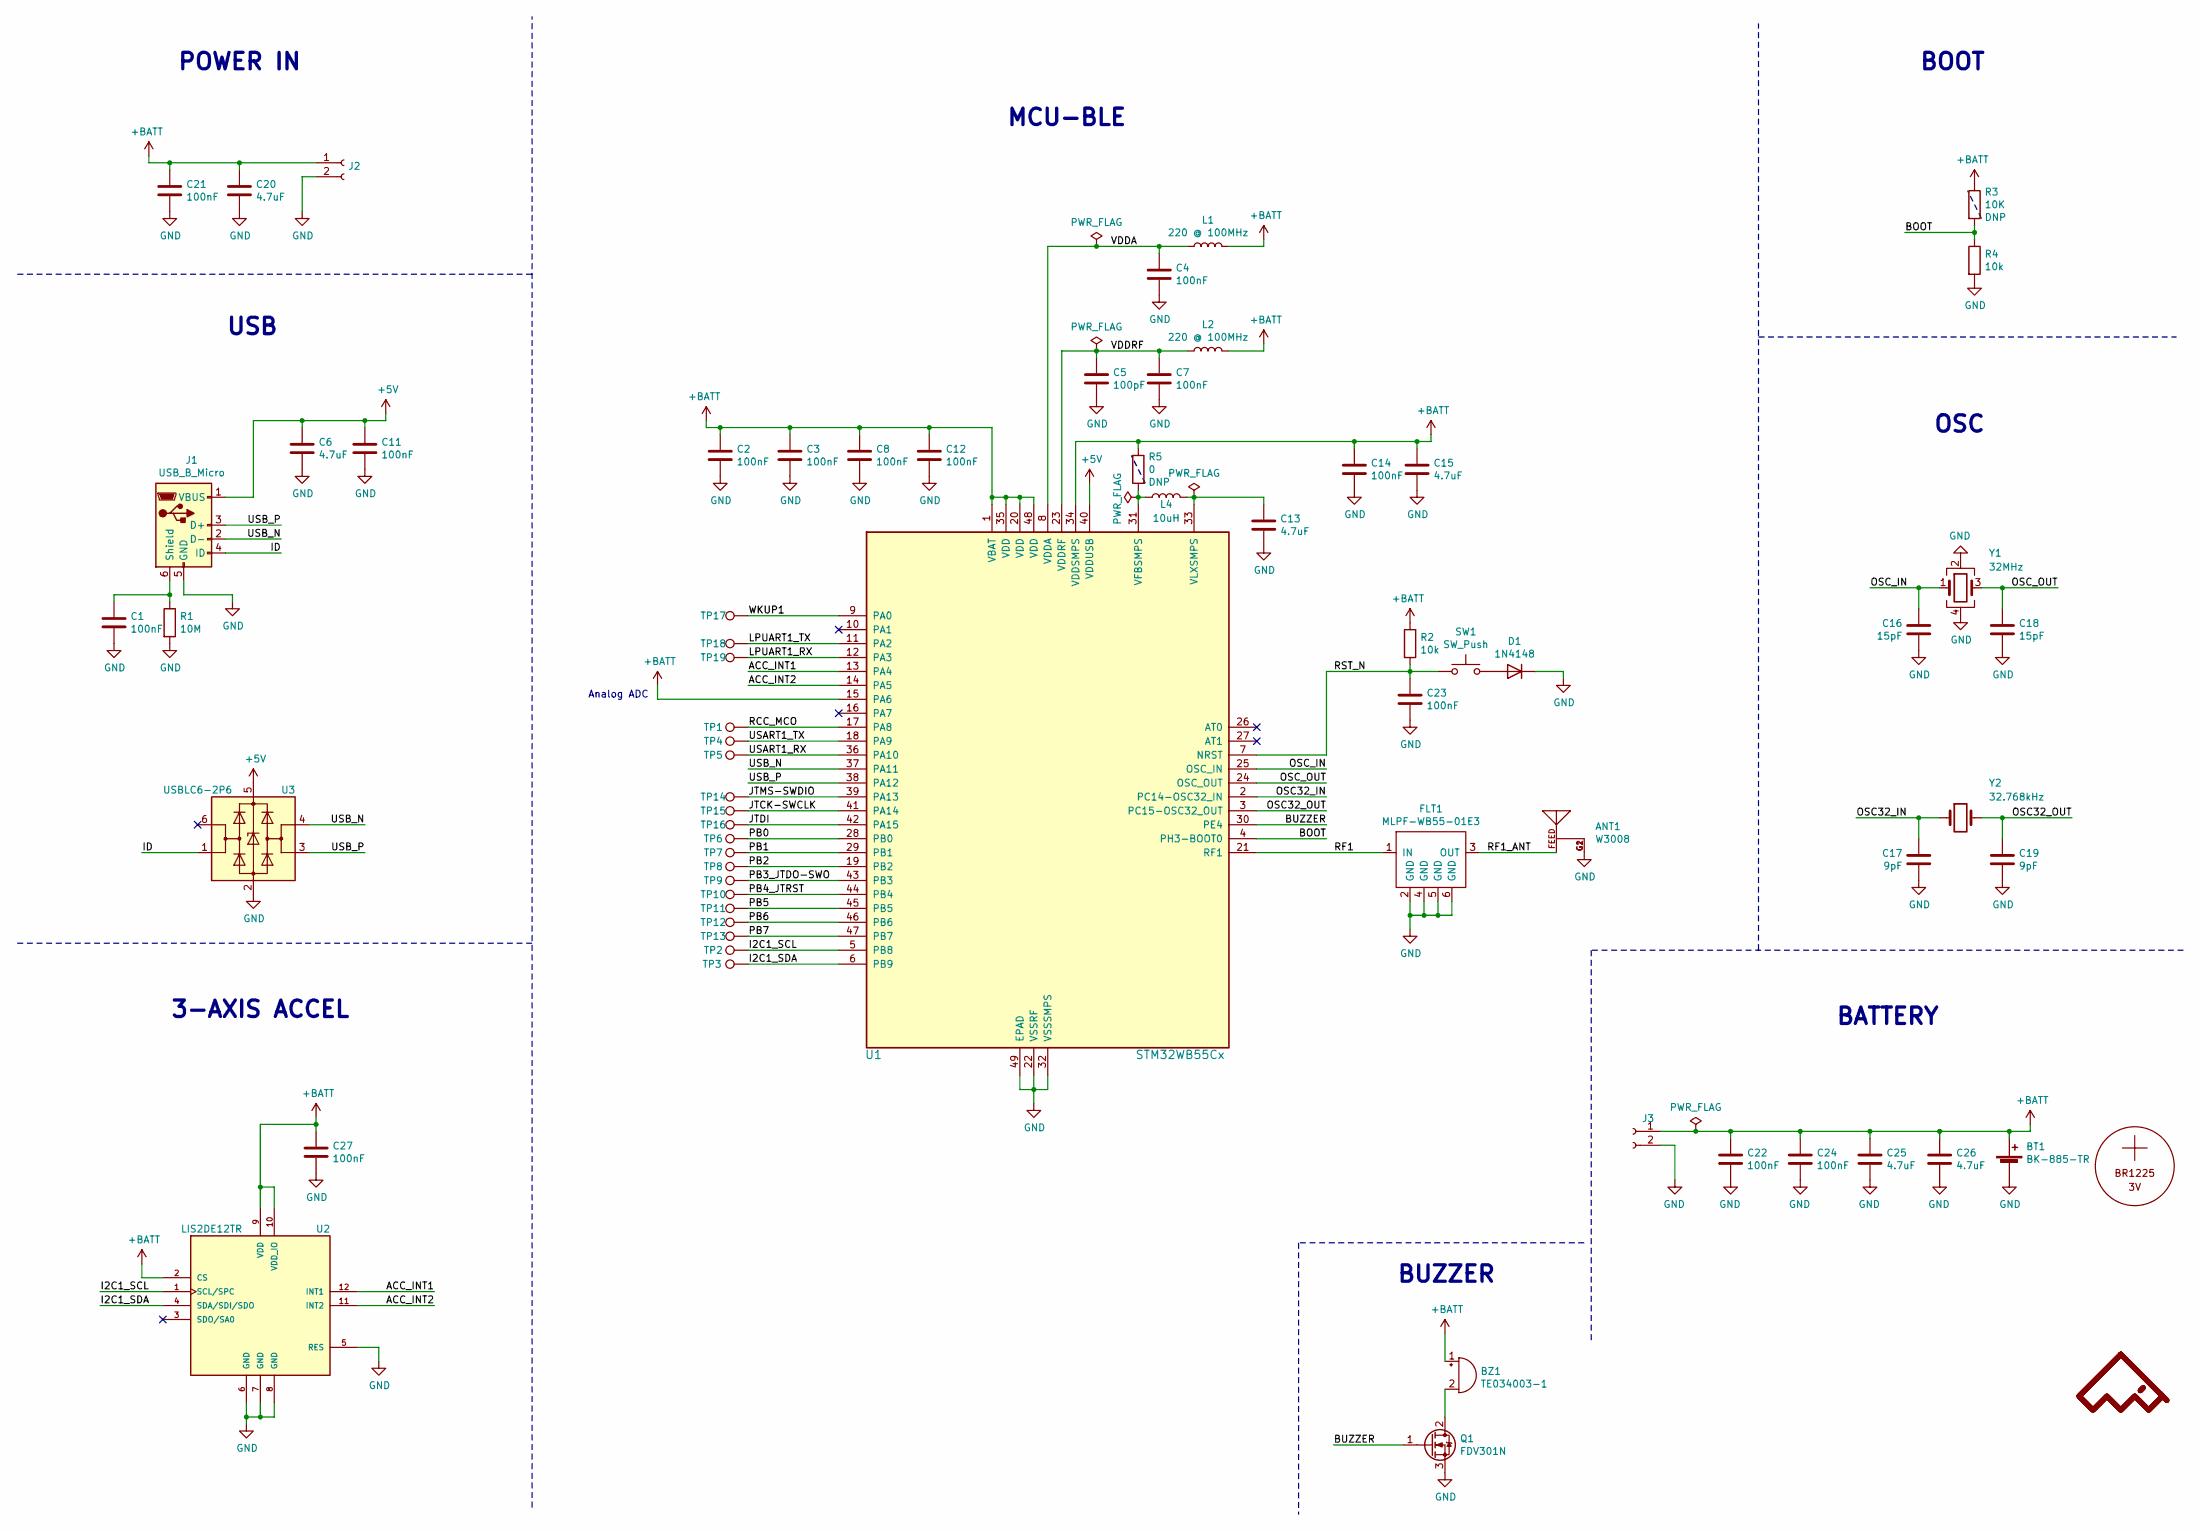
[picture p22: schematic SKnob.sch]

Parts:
ANT1: W3008; mouser# 673-W3008; digikey# 553-1530-1-ND
BATT1: BR1225; digikey# P183-ND
BT1: BK-885-TR; BatteryHolder_Keystone_3000_1x12mm; digikey# BK-885-CT-ND
BZ1: TE034003-1; digikey# 2104-TE034003-1CT-ND
C1, C2, C3, C4, C7, C8, C11, C12, C14, C21, C22, C23, C24, C27: 100nF; C_0402_1005Metric
C5: 100pF; C_0402_1005Metric
C6, C13, C15, C20, C25, C26: 4.7uF; C_0805_2012Metric
C16, C18: 15pF; C_0402_1005Metric
C17, C19: 9pF; C_0402_1005Metric
D1: 1N4148; D_0402_1005Metric; digikey# 1N4148WL2-TPMSCT-ND
FLT1: MLPF-WB55-01E3; mouser# 511-MLPF-WB55-01E3; digikey# 497-19088-1-ND
J1: USB_B_Micro; USB_Micro-B_Molex-105133-0001; mouser# 538-105133-0001; digikey# WM9734CT-ND
J2, J3: Conn_01x02; PinHeader_1x02_P2.00mm_Vertical; mouser# 855-M22-2510246; digikey# 952-2280-ND
L1, L2: 220 @ 100MHz; L_0603_1608Metric; mouser# 810-MPZ1608S221ATD25; digikey# 445-172893-1-ND
L4: 10uH; L_0603_1608Metric; mouser# 963-CBMF1608T100K; digikey# 587-1720-1-ND
Q1: FDV301N; SOT-23; mouser# 512-FDV301N; digikey# FDV301NCT-ND
R1: 10M; R_0402_1005Metric
R2, R4: 10k; R_0402_1005Metric
R3: 10K; R_0402_1005Metric_DNP
R5: 0; R_0402_1005Metric_DNP
SW1: SW_Push; SW_SPST_B3U-3000P; digikey# SW1022CT-ND
T1, T2: LA_LOGO
TP1, TP2, TP3, TP4, TP5, TP6, TP7, TP8, TP9, TP10, TP11, TP12, TP13, TP14, TP15, TP16, TP17, TP18, TP19: TestPoint; TestPoint_Pad_D1.0mm
U1: STM32WB55Cx; mouser# 511-STM32WB55CGU6; digikey# 497-18489-ND
U2: LIS2DE12TR; mouser# 511-LIS2DE12TR; digikey# 497-15997-1-ND
U3: USBLC6-2P6; SOT-666; mouser# 511-STEVAL-IPE023V1; digikey# 497-5026-1-ND
Y1: 32MHz; Crystal_SMD_2016-4Pin_2.0x1.6mm; mouser# 81-XRCGB32M000F1H02R; digikey# 490-18335-1-ND
Y2: 32.768kHz; Crystal_SMD_2012-2Pin_2.0x1.2mm; mouser# 520-.327-9-12R-C-T; digikey# XC2744CT-ND

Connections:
+5V: C6.1, C11.1, J1.1 (VBUS), U1.40 (VDDUSB), U3.5 (VBUS)
+BATT: BT1.1 (+), BZ1.1 (-), C2.1, C3.1, C8.1, C12.1, C14.1, C15.1, C20.1, C21.1, C22.1, C24.1, C25.1, C26.1, C27.1, J2.1, J3.1, L1.2, L2.2, R2.1, R3.1, R5.1, U1.1 (VBAT), U1.15 (PA6), U1.20 (VDD), U1.34 (VDDSMPS), U1.35 (VDD), U1.48 (VDD), U2.2 (CS), U2.9 (VDD), U2.10 (VDD_IO)
/ACC_INT1: U1.13 (PA4), U2.12 (INT1)
/ACC_INT2: U1.14 (PA5), U2.11 (INT2)
/BOOT: R3.2, R4.1, U1.4 (PH3-BOOT0)
/BUZZER: Q1.1 (G), U1.30 (PE4)
/I2C1_SCL: TP2.1, U1.5 (PB8), U2.1 (SCL/SPC)
/I2C1_SDA: TP3.1, U1.6 (PB9), U2.4 (SDA/SDI/SDO)
/ID: J1.4 (ID), U3.1 (I/O1)
/JTCK-SWCLK: TP15.1, U1.41 (PA14)
/JTDI: TP16.1, U1.42 (PA15)
/JTMS-SWDIO: TP14.1, U1.39 (PA13)
/LPUART1_RX: TP19.1, U1.12 (PA3)
/LPUART1_TX: TP18.1, U1.11 (PA2)
/OSC32_IN: C17.1, U1.2 (PC14-OSC32_IN), Y2.1
/OSC32_OUT: C19.1, U1.3 (PC15-OSC32_OUT), Y2.2
/OSC_IN: C16.1, U1.25 (OSC_IN), Y1.1
/OSC_OUT: C18.1, U1.24 (OSC_OUT), Y1.3
/PB0: TP6.1, U1.28 (PB0)
/PB1: TP7.1, U1.29 (PB1)
/PB2: TP8.1, U1.19 (PB2)
/PB3_JTDO-SWO: TP9.1, U1.43 (PB3)
/PB4_JTRST: TP10.1, U1.44 (PB4)
/PB5: TP11.1, U1.45 (PB5)
/PB6: TP12.1, U1.46 (PB6)
/PB7: TP13.1, U1.47 (PB7)
/RCC_MCO: TP1.1, U1.17 (PA8)
/RF1: FLT1.1 (IN), U1.21 (RF1)
/RF1_ANT: ANT1.FEED, FLT1.3 (OUT)
/RST_N: C23.1, R2.2, SW1.1, U1.7 (NRST)
/USART1_RX: TP5.1, U1.36 (PA10)
/USART1_TX: TP4.1, U1.18 (PA9)
/USB_N: J1.2 (D-), U1.37 (PA11), U3.4 (I/O2)
/USB_P: J1.3 (D+), U1.38 (PA12), U3.3 (I/O2)
/VDDA: C4.1, L1.1, U1.8 (VDDA)
/VDDRF: C5.1, C7.1, L2.1, U1.23 (VDDRF)
/WKUP1: TP17.1, U1.9 (PA0)
GND: ANT1.G1 (GND), ANT1.G2 (GND), BT1.2 (-), C1.2, C2.2, C3.2, C4.2, C5.2, C6.2, C7.2, C8.2, C11.2, C12.2, C13.2, C14.2, C15.2, C16.2, C17.2, C18.2, C19.2, C20.2, C21.2, C22.2, C23.2, C24.2, C25.2, C26.2, C27.2, D1.1 (K), FLT1.2 (GND), FLT1.4 (GND), FLT1.5 (GND), FLT1.6 (GND), J1.5 (GND), J2.2, J3.2, Q1.3 (S), R1.2, R4.2, U1.22 (VSSRF), U1.32 (VSSSMPS), U1.49 (EPAD), U2.5 (RES), U2.6 (GND), U2.7 (GND), U2.8 (GND), U3.2 (GND), Y1.2, Y1.4
unnamed: BZ1.2 (+), Q1.2 (D)
unnamed: C1.1, J1.6 (Shield), R1.1
unnamed: C13.1, L4.2, U1.33 (VLXSMPS)
unnamed: D1.2 (A), SW1.2
unnamed: L4.1, R5.2, U1.31 (VFBSMPS)

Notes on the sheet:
Analog ADC
BATTERY
OSC
BOOT
MCU-BLE
POWER IN
USB
3-AXIS ACCEL
BUZZER

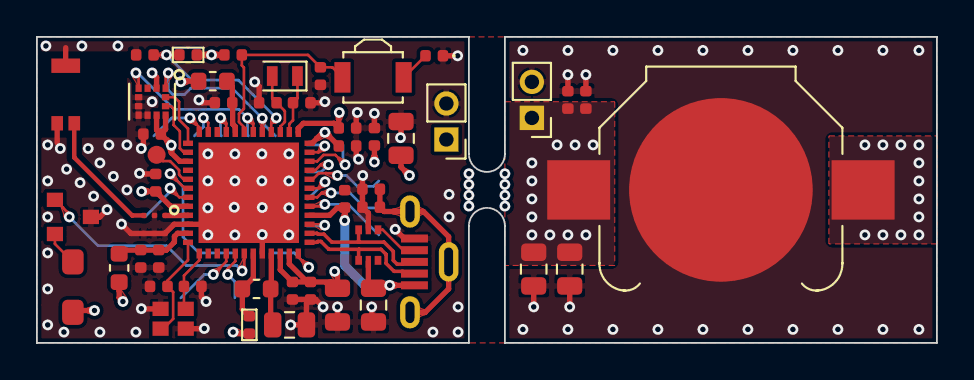
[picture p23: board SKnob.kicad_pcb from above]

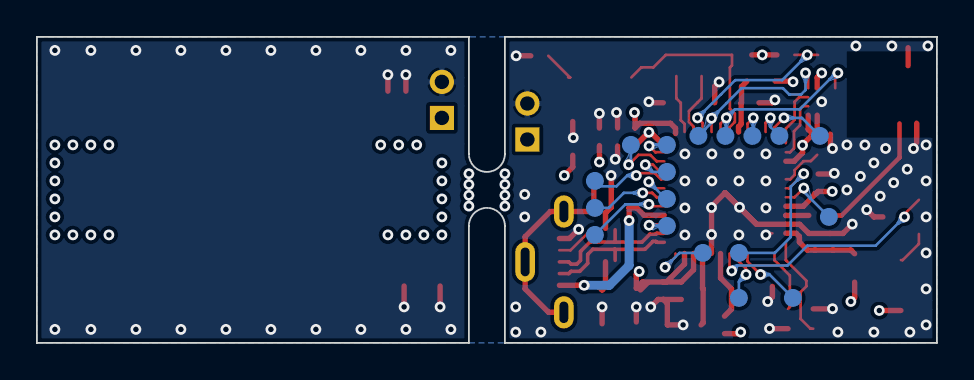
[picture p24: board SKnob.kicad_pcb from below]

Board: 4 copper layers, 50.0 x 17.0 mm, 71 parts (20 on the bottom side), 43 nets.

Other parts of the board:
QR*****: bozica.co

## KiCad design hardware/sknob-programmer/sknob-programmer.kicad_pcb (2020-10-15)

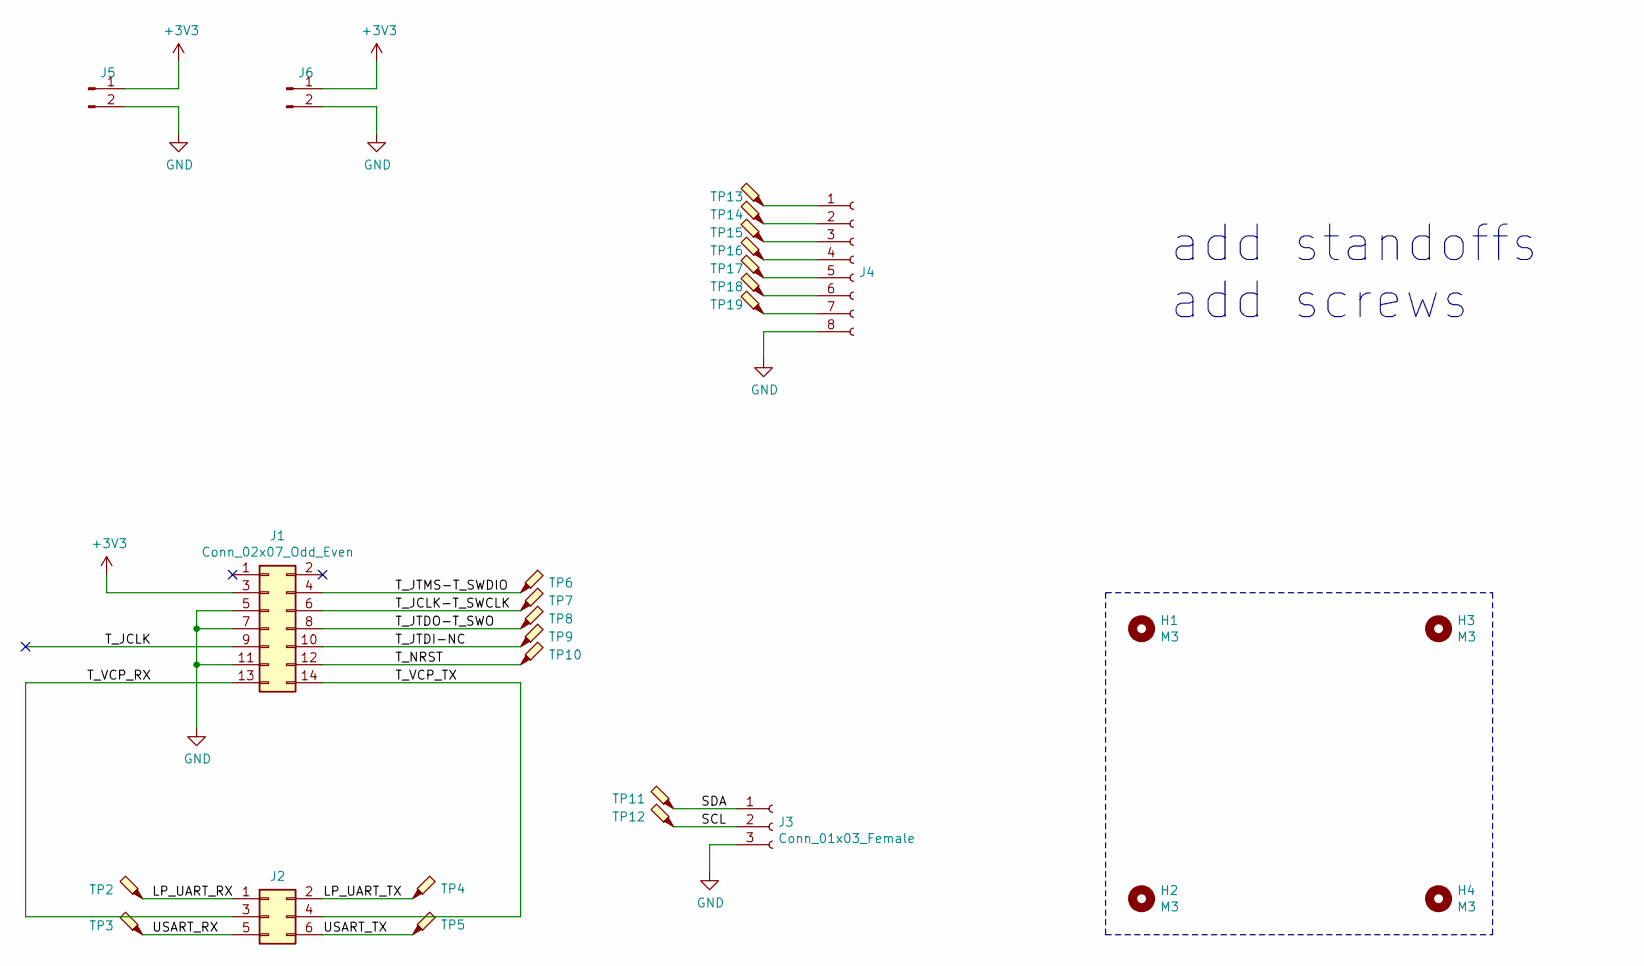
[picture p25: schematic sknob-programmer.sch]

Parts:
H1, H2, H3, H4: M3; MountingHole_3.2mm_M3
J1: Conn_02x07_Odd_Even; PinHeader_2x07_P1.27mm_Vertical
J2: Conn_02x03_Odd_Even; PinHeader_2x03_P2.54mm_Vertical
J3: Conn_01x03_Female; PinHeader_1x03_P2.54mm_Vertical
J4: Conn_01x08_Female; PinSocket_1x08_P2.54mm_Vertical
J5, J6: Conn_01x02_Male; PinHeader_1x02_P2.00mm_Vertical
TP2, TP3, TP4, TP5, TP6, TP7, TP8, TP9, TP10, TP11, TP12, TP13, TP14, TP15, TP16, TP17, TP18, TP19: P13-0123‎; PinHeader_1x01_P1.00mm_Vertical

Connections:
+3V3: J1.3, J5.1, J6.1
/LP_UART_RX: J2.1, TP2.1
/LP_UART_TX: J2.2, TP4.1
/SCL: J3.2, TP12.1
/SDA: J3.1, TP11.1
/T_JCLK-T_SWCLK: J1.6, TP7.1
/T_JTDI-NC: J1.10, TP9.1
/T_JTDO-T_SWO: J1.8, TP8.1
/T_JTMS-T_SWDIO: J1.4, TP6.1
/T_NRST: J1.12, TP10.1
/T_VCP_RX: J1.13, J2.3
/T_VCP_TX: J1.14, J2.4
/USART_RX: J2.5, TP3.1
/USART_TX: J2.6, TP5.1
GND: J1.5, J1.7, J1.11, J3.3, J4.8, J5.2, J6.2
unnamed: J4.1, TP13.1
unnamed: J4.2, TP14.1
unnamed: J4.3, TP15.1
unnamed: J4.4, TP16.1
unnamed: J4.5, TP17.1
unnamed: J4.6, TP18.1
unnamed: J4.7, TP19.1

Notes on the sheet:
add standoffs add screws

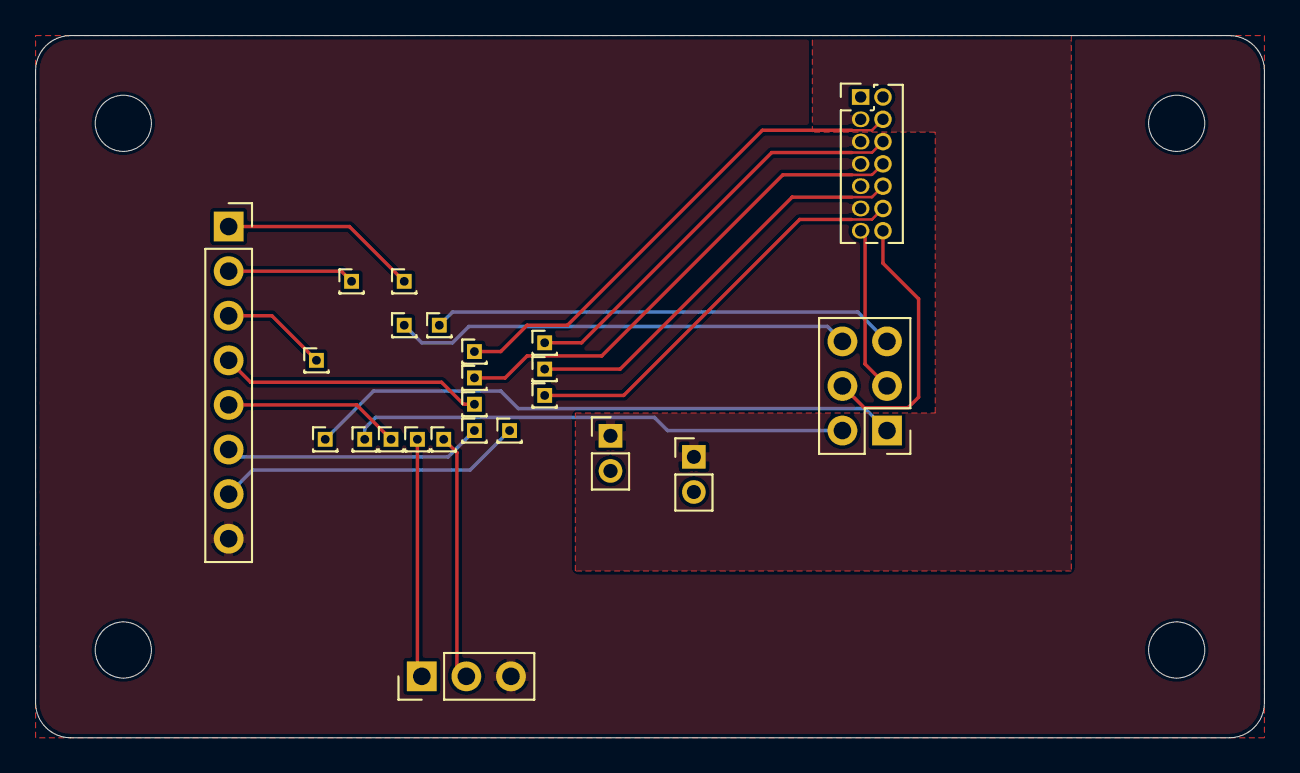
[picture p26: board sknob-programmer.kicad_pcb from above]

Board: 4 copper layers, 70.0 x 40.0 mm, 29 parts (1 on the bottom side), 22 nets.

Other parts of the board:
QR*****: bozica.co

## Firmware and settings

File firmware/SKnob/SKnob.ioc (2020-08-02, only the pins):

Mcu.UserName=STM32WB55CCUx
PA6.GPIO_Label=ADC1_IN11_VBATT
PA12.Signal=USB_DP
PE4.GPIO_Label=BUZZER
PA8.Signal=RCC_MCO
PE4.Signal=GPIO_Output
PA0.Signal=SYS_WKUP1
PB9.Signal=I2C1_SDA
PA6.Signal=ADCx_IN11
PA10.Signal=USART1_RX
PA15.Signal=SYS_JTDI
PA4.GPIO_Label=ACCEL_INT1
PB4.Signal=SYS_JTRST
PA3.Signal=LPUART1_RX
PA11.GPIO_Label=USB_N
PC14-OSC32_IN.Signal=RCC_OSC32_IN
PA12.GPIO_Label=USB_P
PA13.Signal=SYS_JTMS-SWDIO
PA9.Signal=USART1_TX
PC15-OSC32_OUT.Signal=RCC_OSC32_OUT
PA5.Signal=GPIO_Input
PA2.Signal=LPUART1_TX
PB3.Signal=SYS_JTDO-SWO
PA4.Signal=GPIO_Input
PA5.GPIO_Label=ACCEL_INT2
PA11.Signal=USB_DM
PA14.Signal=SYS_JTCK-SWCLK
PB8.Signal=I2C1_SCL

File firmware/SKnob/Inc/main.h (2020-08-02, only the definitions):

#define ACCEL_INT1_Pin GPIO_PIN_4
#define ACCEL_INT1_GPIO_Port GPIOA
#define ACCEL_INT2_Pin GPIO_PIN_5
#define ACCEL_INT2_GPIO_Port GPIOA
#define ADC1_IN11_VBATT_Pin GPIO_PIN_6
#define ADC1_IN11_VBATT_GPIO_Port GPIOA
#define BUZZER_Pin GPIO_PIN_4
#define BUZZER_GPIO_Port GPIOE
#define USB_N_Pin GPIO_PIN_11
#define USB_N_GPIO_Port GPIOA
#define USB_P_Pin GPIO_PIN_12
#define USB_P_GPIO_Port GPIOA

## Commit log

2020-05-20 draft with dimmentions of PCB@
    [SKnob.kicad_pcb, SKnob.sch]
2020-05-24 antena section
    [SKnob.sch]
2020-05-25 rf network
    [SKnob.kicad_pcb, SKnob.sch]
2020-06-01 stm32wb chip selection
    [SKnob.kicad_pcb, SKnob.sch]
2020-06-01 preliminary routing
    [SKnob.kicad_pcb, SKnob.sch]
2020-06-04 added accel
    [SKnob.kicad_pcb, SKnob.sch]
2020-08-02 update hardware to include test points in the back and commit auto generated firmware project files
    [SKnob.kicad_pcb, SKnob.sch]
2020-08-02 finishing touches
    [SKnob.kicad_pcb, SKnob.sch]
2020-08-02 added buzzer to PE4
    [SKnob.kicad_pcb, SKnob.sch]
2020-08-02 hardware Rev 1.0
    [SKnob-B_Cu.gbr, SKnob-B_Mask.gbr, SKnob-B_Paste.gbr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]
2020-08-02 Tag: Rev 1.0
    [SKnob-B_Cu.gbr, SKnob-B_Mask.gbr, SKnob-B_Paste.gbr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]
2020-08-02 remove silk from footprints, replace silk gerber with empty manually
    [SKnob-B_Cu.gbr, SKnob-B_Mask.gbr, SKnob-B_Paste.gbr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]
2020-08-02 shopping carts from digikey and mouser, added mouser part numbers to sch
    [Mouser_Aug02_0217PM.ods, SKnob.sch, digikey_2020-08-02T141608.csv]
2020-10-15 added programmer project
    [SKnob.kicad_pcb, SKnob.step, digikey_2020-08-02T141608.csv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]
2020-10-15 3D holder model for programmer
    [Holder.FCStd]
2020-12-18 pdf bom version

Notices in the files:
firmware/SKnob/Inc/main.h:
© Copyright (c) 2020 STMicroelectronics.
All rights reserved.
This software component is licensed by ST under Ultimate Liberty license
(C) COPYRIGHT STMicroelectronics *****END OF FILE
